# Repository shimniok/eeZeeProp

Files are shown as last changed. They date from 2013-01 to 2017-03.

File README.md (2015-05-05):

eeZeeProp is an affordable breadboard breakout for Parallax Propeller featuring FTDI and PropPlug programming ports, all
GPIO pins broken out, configurable BOE, and flexible power supply options.  It has onboard crystal, regulator, EEPROM,
and current limiting resistors on the serial programming pins.

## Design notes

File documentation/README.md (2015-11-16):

# eeZeeProp User Guide
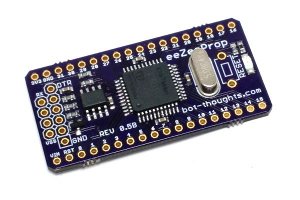
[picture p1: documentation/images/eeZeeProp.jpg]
eeZeeProp


## Introduction

The Parallax Propeller is an amazing, flexible, innovative MCU with 8 cogs running in parallel. The eeZeeProp breakout brings all this power to the breadboard. The board includes onboard regulator, eeprom, power LED, crystal---everything you need and nothing you don't. Plus you can program it either with an FTDI programmer *or* Prop Plug programmer.

Want one? [Buy on Tindie](https://tindie.com/shops/bot_thoughts/eezee-propeller/)

**NOTE:** If you have an older, Rev 0.2 board, see [the Rev 0.2 documentation](eeZeePropRev2.md)

## Pinout

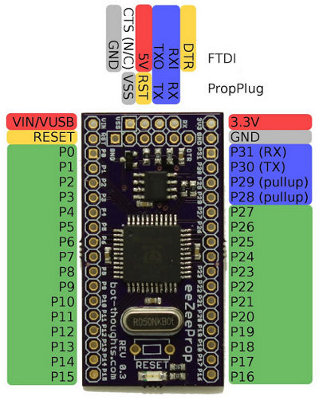
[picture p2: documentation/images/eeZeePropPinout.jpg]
eeZeePropPinout


## How to Assemble

### Pin Headers

* Install the two 18-pin headers on a breakout board, 9 rows apart.
* Place the eeZeeProp, Propeller side up, on the pin headers.
* Solder the pin headers.

### Switch

* Remove the eeZeeProp from the breadboard.
* Install the switch and bend the pins if necessary to hold it in place.
* Solder the switch from the bottom and then, optionally, from the top.

### Programming header

* Provided are two 6-pin headers, one right angle, one vertical.
* If you're going to use both FTDI and Prop Plug, use the right angle header for Prop Plug.
* To use either with FTDI, install. To use either with the Prop Plug, break off two pins.
* Install the header(s) and carefully hold in place at the RX/DTR side, and don't touch the other side.
* Solder *only* the ```GND``` or ```VSS``` pin, opposite your finger.
* Check vertical alignment of the pin header and adjust while re-soldering the ```GND``` or ```VSS``` pin.
* Once aligned, solder the remaining pins.

## Getting Started

### Examples, Help, Community

* [Propeller Documentation](http://www.parallaxsemiconductor.com/docs)
* [Resource Index](https://forums.parallax.com/discussion/111166/propeller-resource-index) on Propeller 1 Forums
* Lots of smart people willing to help on the [Parallax Propeller 1 Forum](https://forums.parallax.com/categories/propeller-1-multicore-microcontroller)
* Find example programs in the [examples](../examples) directory of this repo.
* Useful objects can be found on the [OBEX](http://obex.parallax.com/) (Propeller Object Exchange)

### IDE

The following are IDEs that I recommend for Propeller programming:

  * [PropellerIDE](https://github.com/parallaxinc/PropellerIDE) for Spin/PASM development
  * [SimpleIDE](http://learn.parallax.com/propeller-c-set-simpleide) and [PropGCC](http://code.google.com/p/propgcc/) for writing in C

### Chip Programming

You can either use a 5V FTDI, 3.3V FTDI or Prop Plug to program your eeZee Prop (see *Power Options* below). Pay careful attention to the pin labels. For FTDI, the pins are labeled ```DTR``` (aka GRN aka Green) and ```GND``` (aka BLK aka Black). For Prop Plug the pins are labeled ```RX``` and ```VSS```.

Other serial adapters can be made to work, you just need a programmer with DTR, RX, TX, and GND.

  * Vcc -> (opt) tie to power, or see Power below
  * RXI -> tie to receive (prop out, pc in)
  * TXO -> tie to transmit (prop in, pc out)
  * DTR -> this resets the prop
  * GND -> ground

## Powering the Board

The eeZeeProp provides lots of flexibility. You can power from FTDI, from an external source, or an external 3.3V source. If you are using a 3.3V FTDI, connect the ```3V3FTDI``` solder jumper.

You can still use the FTDI even if the board is powered externally, because Schottky diodes prevent current flowing from one supply (FTDI or VIN) back into the other.

### Limits

```VIN``` Pin input voltage: 4.8V-6.0V @ 800mA; 4.7V-6.0V @ 100mA, room temperature. Lower input voltages are typically possible but not guaranteed in all scenarios.

Higher input voltages are acceptable on boards of Rev 0.4 and newer. The onboard regulator is either an STM LD1117-33 ([datasheet.pdf](http://www.st.com/web/en/resource/technical/document/datasheet/CD00000544.pdf)), or OnSemi NCP1117 ([datasheet.pdf](http://www.onsemi.com/pub_link/Collateral/NCP1117-D.PDF)) and can support higher voltages, but you'll need to be careful of temperatures and load current.

### Solder Jumpers

 * ```3V3FTDI``` is used when you have a FTDI programmer supplying 3.3V (rather than 5V).
 * ```BYPASS``` bypasses the VIN Schottky diode; power on FTDI appears on VIN.

### Keep It Simple

Use a 5V FTDI and leave ```BYPASS``` and ```3V3FTDI``` disconnected. If you are using a 3.3V FTDI, connect the ```3V3FTDI``` solder jumper and leave ```BYPASS``` disconnected.  In either case you can optionally add an external power supply to VIN.

*Configured for 5V FTDI + external power supply on VIN*:
![Solder Jumpers](images/eeZeePropJumpers.jpg)

### Advanced Options

| BYPASS       | 3V3FTDI      | VIN pin             | 3V3 pin     | 5V FTDI | 3.3V FTDI |
|--------------|--------------|---------------------|-------------|---------|-----------|
| Disconnected | Disconnected | External Supply ok. | 3.3V Output | Ok      | NO        |
| Disconnected | Connected    | External Supply ok. | 3.3V Output | NO      | Ok        |
| Connected    | Disconnected | OUTPUT ONLY, 5V     | 3.3V Output | Ok      | NO        |
| Connected    | Connected    | OUTPUT ONLY, 3.3V   | 3.3V Output | NO      | Ok        |

Note: with ```BYPASS``` soldered, the ```VIN``` pin becomes output *only* and cannot be used as voltage input without potentially damaging the FTDI.

## BOE

BOE is Brown-Out Enable, which causes a shutdown/reset when power falls below a certain level. To enable it, connect the ```BOE``` solder jumper to the ```GND``` side.  To disable, connect ```BOE``` to the ```VCC``` side.

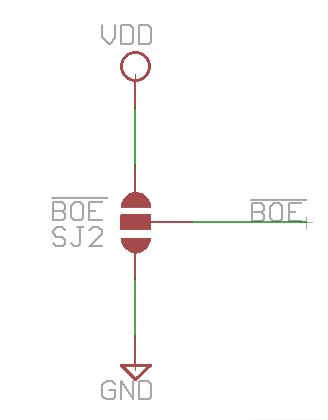
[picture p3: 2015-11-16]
documentation/images/eeZeePropBOE.png

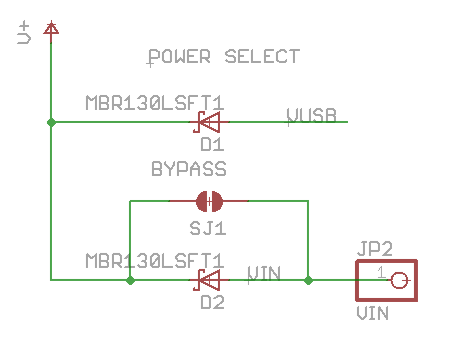
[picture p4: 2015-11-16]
documentation/images/eeZeePropPower1.png

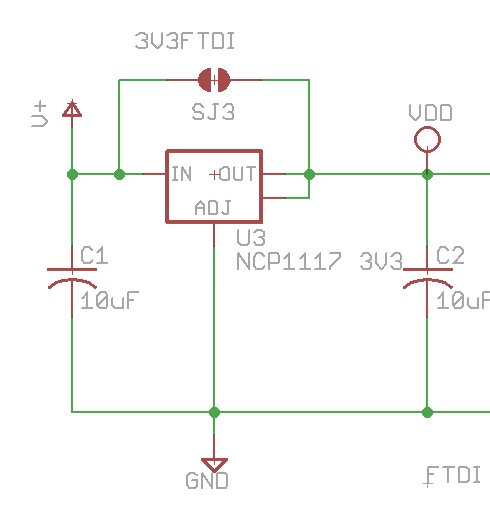
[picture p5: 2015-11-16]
documentation/images/eeZeePropPower2.png

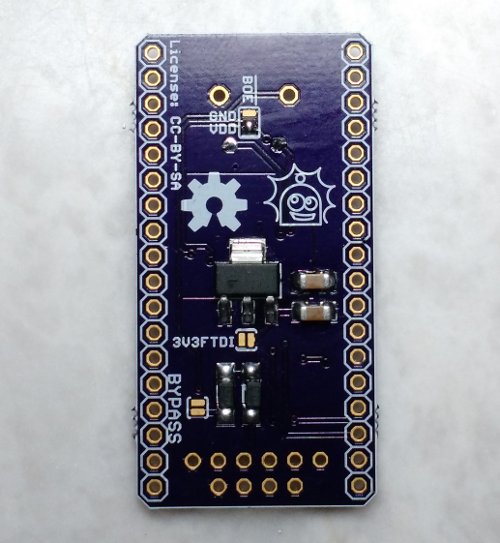
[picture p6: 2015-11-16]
documentation/images/eeZeePropJumpers.jpg

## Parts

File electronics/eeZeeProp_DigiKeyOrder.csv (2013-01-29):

Digi-Key Part Number | Manufacturer Name | Manufacturer Part Number | Customer Reference | Quantity 1 | Quantity 2 | Quantity 3
478-1239-1-ND | AVX | 0603YC104KAT2A | ? | 5 | ? | ?
CAT24C256WI-GT3OSCT-ND | OnSemi | CAT24C256WI-GT3 | ? | 1 | ? | ?
P10KGCT-ND | Panasonic | ERJ-3GEYJ103V | ? | 3 | ? | ?
P330GCT-ND | Panasonic | ERJ-3GEYJ331V | ? | 1 | ? | ?
300-8475-ND | Citizen | HC49US-5.000MABJ-UB | ? | 1 | ? | ?
475-1407-1-ND | OSRAM | LG N971-KN-1 | ? | 1 | ? | ?
MBR130LSFT1GOSCT-ND | On Semi | MBR130LSFT1G | ? | 2 | ? | ?
679-2452-ND | APEM | MJTP1243 | ? | 1 | ? | ?
MMBT3904LT3GOSCT-ND | ON Semi | MMBT3904LT3G | ? | 1 | ? | ?
NCP1117ST33T3GOSCT-ND | On Semi | NCP1117ST33T3G | ? | 1 | ? | ?
P8X32A-Q44-ND | Parallax | P8X32A-Q44 | ? | 1 | ? | ?
311-1.0KGRCT-ND | Yaego | RC0603JR-071KL | ? | 3 | ? | ?
399-3685-1-ND | Kemet | T491A106M006AT | ? | 2 | ? | ?

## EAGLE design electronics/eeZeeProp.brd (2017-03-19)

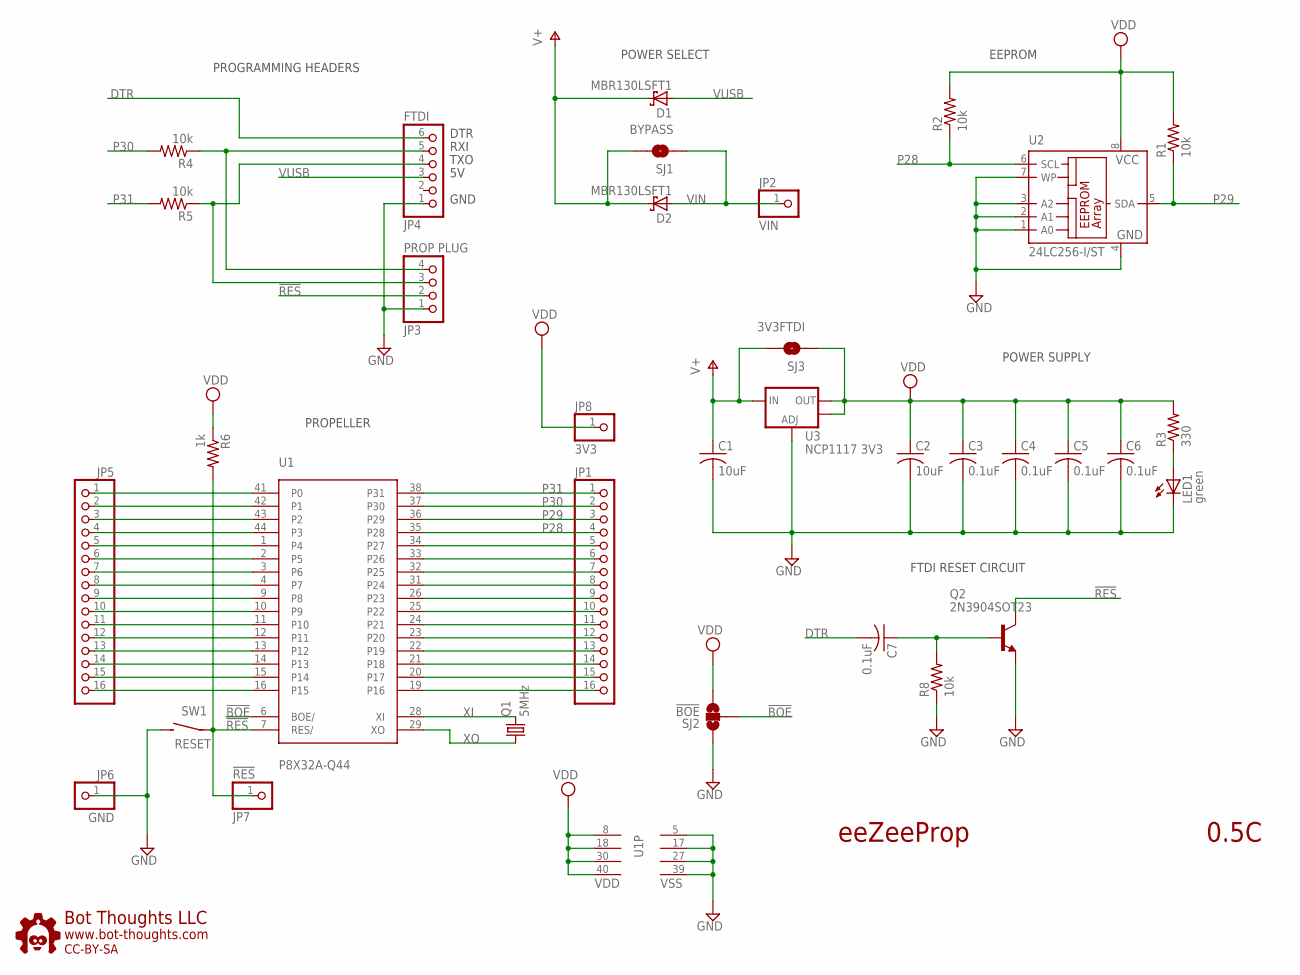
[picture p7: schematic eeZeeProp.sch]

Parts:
C1, C2: 10uF; C1206; PARTNO T491A106M006AT
C3, C4, C5, C6, C7: 0.1uF; C0603; PARTNO 0603YC104KAT2A
D1, D2: MBR130LSFT1; SOD123FL; PARTNO MBR130LSFT1G
JP1, JP5: PINHD-1X16_2.54-S; 1X16-S
JP2: VIN; 1X01
JP3: PROP PLUG; 1X04-S
JP4: FTDI; 1X06-S; PARTNO 2211S-06G
JP6: GND; 1X01
JP7: !RES; 1X01
JP8: 3V3; 1X01
LED1: green; CHIPLED_1206; PARTNO LG N971-KN-1
Q1: 5MHz; HC49U-V; PARTNO HC49US-5.000MABJ-UB
Q2: 2N3904SOT23; SOT-23; PARTNO MMBT3904LT3G
R1, R2, R8: 10k; R0603; PARTNO ERJ-3GEYJ103V
R3: 330; R0603; PARTNO ERJ-3GEYJ331V
R4, R5: 10k; R0603; PARTNO RC0603JR-071KL
R6: 1k; R0603; PARTNO RC0603JR-071KL
SJ1: BYPASS; SJ_2S-NO
SJ2: !BOE; SJ_3
SJ3: 3V3FTDI; SJ_2S-NO
SW1: RESET; 6MMTACTILE_RECT; PARTNO MJTP1243
U1: P8X32A-Q44; PARTNO P8X32A-Q44
U2: 24LC256-I/ST; SO-08; MPN CAT24C256WI-GT3
U3: NCP1117 3V3; SOT223; PARTNO NCP1117ST33T3G
U$1: BTLOGO-LOGO-MD; BTLOGOM

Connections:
!BOE: SJ2.2, U1.6 (BOE/)
!RES: JP3.2, JP7.1, Q2.1 (C), R6.2, SW1.P$1, U1.7 (RES/)
DTR: C7.2, JP4.6
GND: C1.2, C2.2, C3.2, C4.2, C5.2, C6.2, JP3.1, JP4.1, JP6.1, LED1.C, Q2.2 (E), R8.1, SJ2.1, SW1.P$2 (S), U1.5 (VSS), U1.17 (VSS), U1.27 (VSS), U1.39 (VSS), U2.1 (A0), U2.2 (A1), U2.3 (A2), U2.4 (GND), U2.7 (WP), U3.1 (ADJ)
unnamed: JP5.1, U1.41 (P0)
unnamed: JP5.2, U1.42 (P1)
unnamed: JP5.3, U1.43 (P2)
unnamed: JP5.4, U1.44 (P3)
unnamed: LED1.A, R3.1
unnamed: JP5.5, U1.1 (P4)
unnamed: JP5.6, U1.2 (P5)
unnamed: JP5.7, U1.3 (P6)
unnamed: JP5.8, U1.4 (P7)
unnamed: JP5.9, U1.9 (P8)
unnamed: JP5.10, U1.10 (P9)
unnamed: JP5.11, U1.11 (P10)
unnamed: JP5.12, U1.12 (P11)
unnamed: JP5.13, U1.13 (P12)
unnamed: JP5.14, U1.14 (P13)
unnamed: JP5.15, U1.15 (P14)
unnamed: JP5.16, U1.16 (P15)
unnamed: JP1.5, U1.34 (P27)
unnamed: JP1.6, U1.33 (P26)
unnamed: JP1.7, U1.32 (P25)
unnamed: JP1.8, U1.31 (P24)
unnamed: JP1.9, U1.26 (P23)
unnamed: JP1.10, U1.25 (P22)
unnamed: JP1.11, U1.24 (P21)
unnamed: JP1.12, U1.23 (P20)
unnamed: JP1.13, U1.22 (P19)
unnamed: JP1.14, U1.21 (P18)
unnamed: JP1.15, U1.20 (P17)
unnamed: JP1.16, U1.19 (P16)
unnamed: C7.1, Q2.3 (B), R8.2
P28: JP1.4, R2.1, U1.35 (P28), U2.6 (SCL)
P29: JP1.3, R1.1, U1.36 (P29), U2.5 (SDA)
P30: JP1.2, R4.2, U1.37 (P30)
P31: JP1.1, R5.2, U1.38 (P31)
RXI: JP3.4, JP4.5, R4.1
TXO: JP3.3, JP4.4, R5.1
V+: C1.1, D1.C, D2.C, SJ1.2, SJ3.2, U3.3 (IN)
VDD: C2.1, C3.1, C4.1, C5.1, C6.1, JP8.1, R1.2, R2.2, R3.2, R6.1, SJ2.3, SJ3.1, U1.8 (VDD), U1.18 (VDD), U1.30 (VDD), U1.40 (VDD), U2.8 (VCC), U3.2 (OUT), U3.4 (OUT)
VIN: D2.A, JP2.1, SJ1.1
VUSB: D1.A, JP4.3
XI: Q1.2, U1.28 (XI)
XO: Q1.1, U1.29 (XO)

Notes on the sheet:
!BOE
eeZeeProp
0.5C
RXI
TXO
DTR
GND
FTDI RESET CIRCUIT
POWER SUPPLY
POWER SELECT
PROGRAMMING HEADERS
EEPROM
PROPELLER

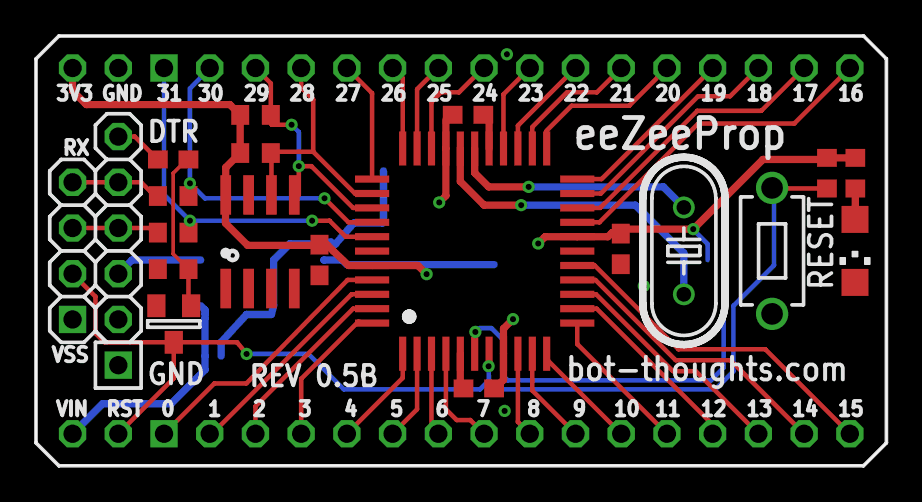
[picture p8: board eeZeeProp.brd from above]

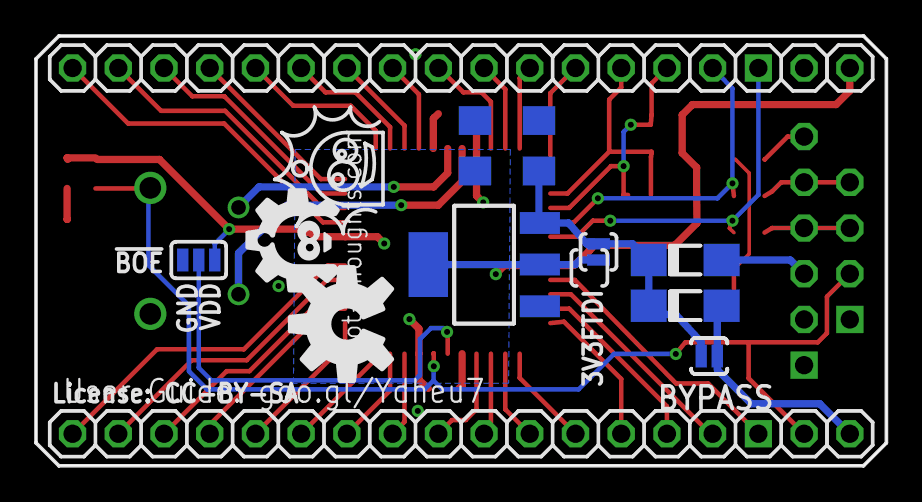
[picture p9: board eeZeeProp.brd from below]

Board: 2 copper layers, 47.2 x 23.9 mm, 35 parts (15 on the bottom side), 46 nets.

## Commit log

2012-11-23 Revision 0.2
    [eeZeeProp.brd, eeZeeProp.sch, eeZeeProp_DigiKeyOrder.csv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]
2012-12-11 Rev 0.2 as built
    [eeZeeProp.sch]
2012-12-28 Revised reset circuit, added bypass for VIN diode, added BOE solder jumper
    [eeZeeProp.brd, eeZeeProp.sch]
2013-01-02 Rev 0.3 as-ordered
    [eeZeeProp.brd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]
2013-01-29 Enlarged pads for SOT-23 and SOD123F for easier hand assembly. Slight tweaks to traces.
    [eeZeeProp.brd, eeZeeProp.sch]
2013-02-04 Minor layout tweaks
    [eeZeeProp.brd]
2013-08-06 Version 0.4, changes some footprints for easier rework, some mods to routing, mitered corners, some other stuff I'm forgetting.
    [eeZeeProp.brd, eeZeeProp.sch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]
2013-11-11 Adding firmware examples into subdirectory. Moving electronics cad into electronics directory.
    [eeZeeProp.brd, eeZeeProp.sch, eeZeeProp_DigiKeyOrder.csv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]
2013-12-11 Added regulator bypass option for 3.3V FTDI. Increased diode pad sizes.
    [eeZeeProp.brd, eeZeeProp.sch]
2014-02-04 Fixed silkscreen conflicts. Enlarged DTR/GND labels. Moved other silk labels to different layer, disabled bottom name silk gen.
    [eeZeeProp.brd, eeZeeProp.sch]
2014-04-15 Revised diode placement, silk, pin 1 dot on propeller.
    [eeZeeProp.brd, eeZeeProp.sch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]
2014-10-17 Changed to 8mil spacing, revised all PTH pins to octagon, relocated traces, vias for clearance. Resized traces with clearance problems.
    [eeZeeProp.brd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]
2015-04-24 updated gerbers for latest production run
2015-11-16 added solder jumper pic
2015-11-16 added pic for solder jumpers
2017-03-19 Revised silkscreen labels, added user guide link, minor relocation of 3v3 ftdi solder jumper and label, updated bt logo
    [eeZeeProp.brd, eeZeeProp.sch]

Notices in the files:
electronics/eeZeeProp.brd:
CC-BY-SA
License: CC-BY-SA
